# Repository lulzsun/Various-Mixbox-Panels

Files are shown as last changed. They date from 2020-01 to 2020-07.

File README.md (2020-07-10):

# Various Mixbox Panels
Vector files for a DIY mixbox layout for various arcade controller brands 

* [Mayflash F500](https://github.com/lulzsun/Various-Mixbox-Panels/tree/master/Mayflash%20F500)
* [Madcatz TE2](https://github.com/lulzsun/Various-Mixbox-Panels/tree/master/Madcatz%20TE2)
* [Madcatz TE & TES](https://github.com/lulzsun/Various-Mixbox-Panels/tree/master/Madcatz%20TE%20%26%20TES)

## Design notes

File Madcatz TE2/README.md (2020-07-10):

# Madcatz TE2 Mixbox Panel
Vector files for a DIY mixbox arcade controller mod for Madcatz TE2

Please read this throughly befoe making any decisions.

There are two files:
* mixbox_te2_metal_panel.dxf - required, the metal control panel that holds the switches and buttons
* mixbox_te2_plexi_panel.dxf - optional but recommended, clear panel to slide artwork under

Do note that the holes on the panel must be chamfered so that screws sit flushed with the metal control panel. The file provided *will not be chamfered* and you are required to do this with some tools (hand drill or drill press).
The steps below are what I recommend you do if you are ordering all these parts online:

Order the metal panel from [Laserboost](https://www.laserboost.com/) with the following configurations:
* Material: 304 Stainless Steel Unfinished (you can decide, but this is the cheaper option)
* Thickness: 1.5 mm
* Size: 304 x 179 mm
* Path Length: 2094 mm

After recieving the metal panel, you must chamfer the screw holes in order for the scews to sit flushed. I've done this using a hand drill mounted in a drill press-like rig, eyeballing and checking until the screw sits flushed.

Order the plexi panel from [Ponoko](https://make.ponoko.com) with the following configurations:
* Material: Clear PETG
* Thickness: 1.0 mm
* Size: 331.50 x 202.20 mm

You have two options on Material and Thickness depending on what you need. Some TE2 models come with [button spacers](https://focusattack.com/t-e-2-spacer-for-sanwa-30mm-obs-series-pushbuttons-8-pak/), which I would recommend using the above configurations for the best fit. However if you don't have the spacers or choose to not use them, you can ty ordering the following configurations below:
* Material: Clear Acrylic
* Thickness: 1.5 mm
* Size: 331.50 x 202.20 mm

Another huge concern to note, I've made some untested dimension adjustments to the plexi panel. Long story short, the first time I designed the files, the plexi dimensions were a bit too big and I had to trim it down with scissors. I have resized it using some error-prone measuring tools (crappy calipers) but have not tested it by reordering. If you order the plexi material as PETG, it will be very easy to trim down with scissors if you find that it still fits a little too big. Let me know how it goes if you are trying out this panel mod.

Good luck!

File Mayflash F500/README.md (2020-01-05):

# Mayflash F500 Mixbox Panel
Vector files for a DIY mixbox arcade controller mod for Mayflash F500

There are two different versions:
* ponoko_f500_mixbox_v1.svg - has rounded key edges
* ponoko_f500_mixbox_v2.svg - has sharp key edges

These files are ready to be uploaded to [Ponoko](https://make.ponoko.com) to be laser cut. 
Here is the configuration for ordering:

* Acrylic - Clear 
* 2mm (0.080 inches)

You will also need new mounting screws:
* M3 x 12mm - Socket or Phillips head 
> (If you are using 0.118 thickness, M3 x 14mm should work better)

# Notes
I recommend you to use 2mm (0.080 inches) plexi thickness because 3mm (0.118 inches) bulges out of the top a little bit.

Originally, the stock front plexiglass is 3mm while the control panel is 2mm. But with these vector files, I have put both the plexiglass and the control panel onto the same sheet, so when you order on Ponoko (or anywhere else), you save on costs by only ordering one sheet of plexiglass and not two of different thicknesses. If you want to be perfect, you can edit the vector file, seperate the control panel and front plexiglass into two files, then have them cut out on their own original thickness. 

2.5mm plexi thickness might be the best option if you can source it. 2mm might not sit completely flush. Let me know the results if you end up trying 2.5mm.

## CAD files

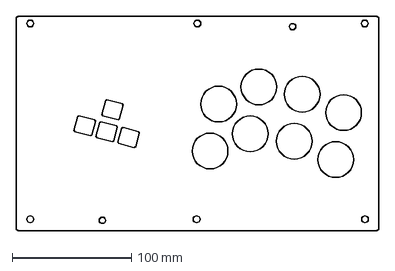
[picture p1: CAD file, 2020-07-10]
Madcatz TE2/mixbox_te2_metal_panel.dxf
304.0 x 179.5 mm

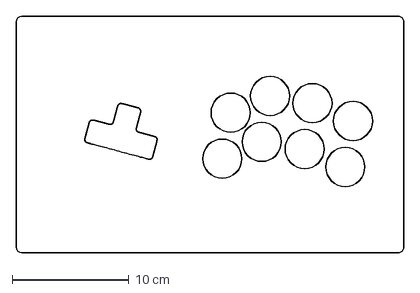
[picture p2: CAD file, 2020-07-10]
Madcatz TE2/mixbox_te2_plexi_panel.dxf
33.2 x 20.2 cm

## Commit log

2020-01-05 Update README.md
    2mm recommendation
2020-07-10 TE2 mixbox files
    [mixbox_te2_metal_panel.dxf, mixbox_te2_plexi_panel.dxf]
